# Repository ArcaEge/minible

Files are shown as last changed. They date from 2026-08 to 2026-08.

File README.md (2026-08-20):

<div align="center">
    <h1>
        minible
    </h1>
    <p>
        <strong>
            very mini devboard with BLE and USB
        </strong>
    </p>
    <p>
        <a href="#features">features</a> •
        <a href="#pcb">PCB</a> •
        <a href="#schematics">schematics</a>
    </p>
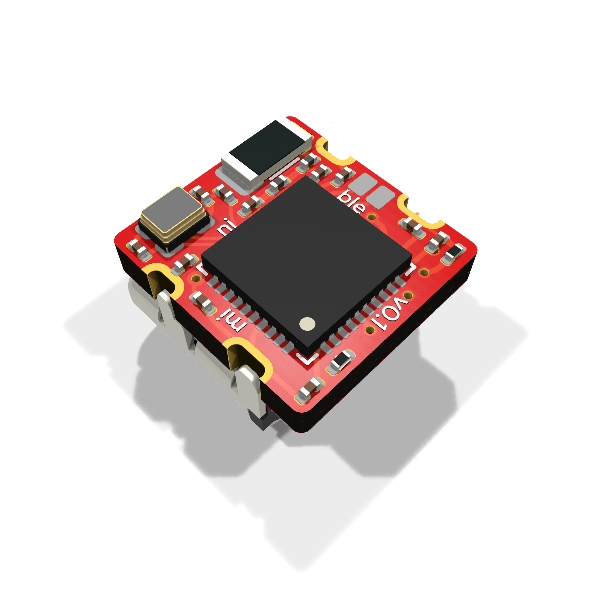
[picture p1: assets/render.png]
render
    
    PCB
</div>

## features

- tiny! just 8.5*9mm
- based on the nRF52833
- USB-C (full speed)
- 2 GPIOs (1 analog input)
    - P0.05, P0.11
- BLE, Thread, Matter, ANT support

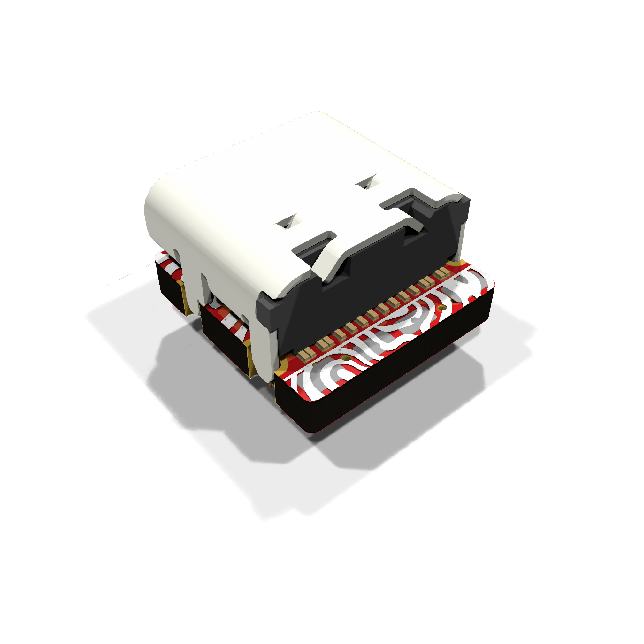
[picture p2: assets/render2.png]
render


## PCB

Production and BOM files are under `production/`

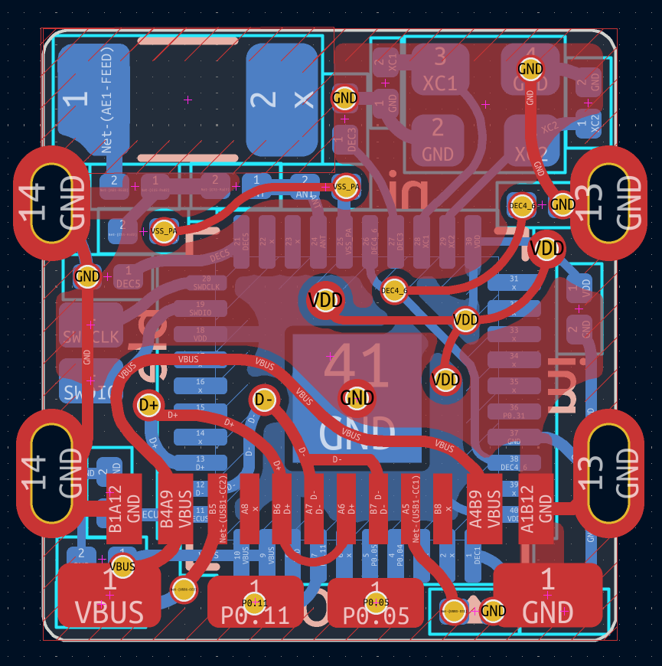
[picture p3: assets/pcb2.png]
PCB


## schematics

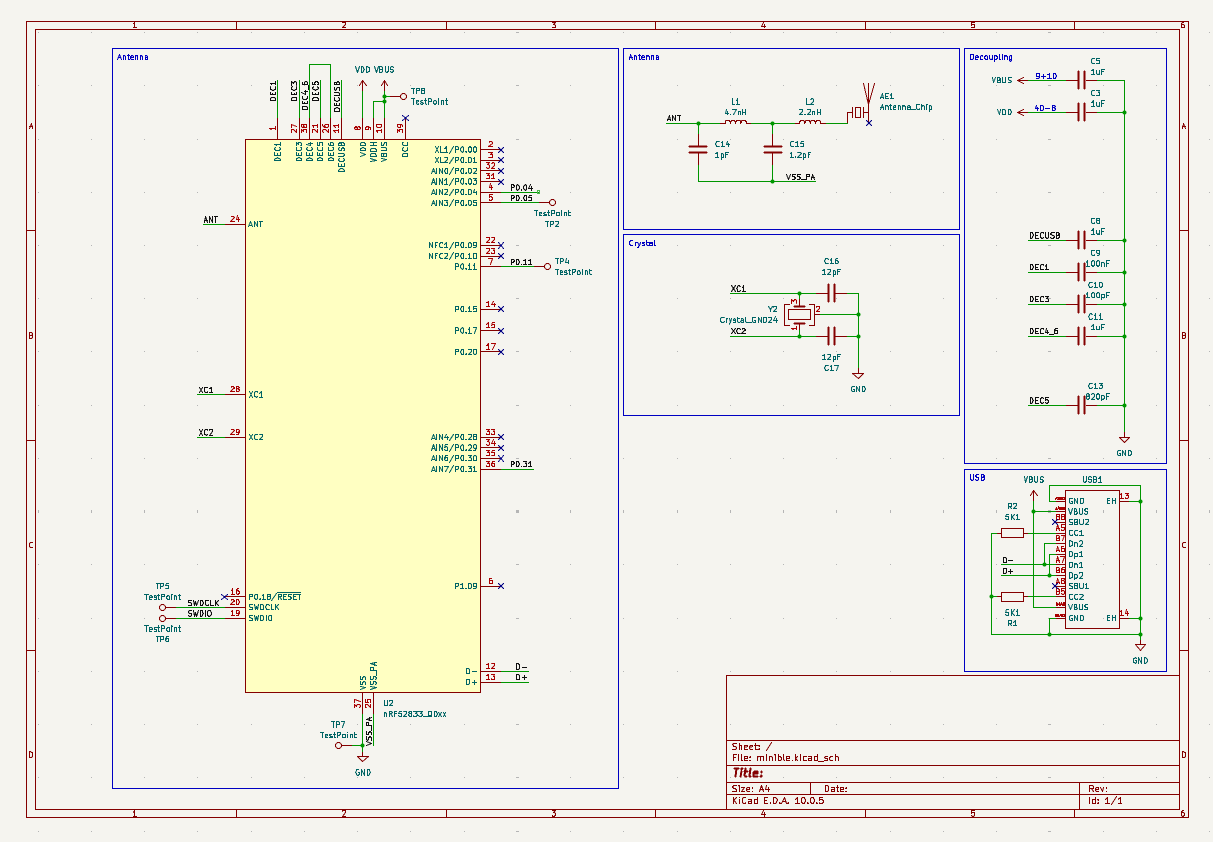
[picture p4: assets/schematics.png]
schematics


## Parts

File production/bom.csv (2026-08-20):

Reference | Qty | Value | Supplier | Supplier Part | Supplier Part URL | Footprint | Datasheet
AE1 | 1 | Antenna_Chip | LCSC | C127620 | https://www.lcsc.com/product-detail/C127620.html | Resistor_SMD:R_1206_3216Metric
C3,C5,C8,C11 | 4 | 1uF | LCSC | C76930 | https://www.lcsc.com/product-detail/C76930.html | Capacitor_SMD:C_0201_0603Metric
C9 | 1 | 100nF | LCSC | C307380 | https://www.lcsc.com/product-detail/C307380.html | Capacitor_SMD:C_0201_0603Metric
C10 | 1 | 100pF | LCSC | C272870 | https://www.lcsc.com/product-detail/C272870.html | Capacitor_SMD:C_0201_0603Metric
C13 | 1 | 820pF | LCSC | C2836759 | https://www.lcsc.com/product-detail/C2836759.html | Capacitor_SMD:C_0201_0603Metric
C14 | 1 | 1pF | LCSC | C20069198 | https://www.lcsc.com/product-detail/C20069198.html | Capacitor_SMD:C_0201_0603Metric
C15 | 1 | 1.2pF | LCSC | C48642883 | https://www.lcsc.com/product-detail/C48642883.html | Capacitor_SMD:C_0201_0603Metric
C16,C17 | 2 | 12pF | LCSC | C50391 | https://www.lcsc.com/product-detail/C50391.html | Capacitor_SMD:C_0201_0603Metric
L1 | 1 | 4.7nH | LCSC | C3910459 | https://www.lcsc.com/product-detail/C3910459.html | Inductor_SMD:L_0201_0603Metric
L2 | 1 | 2.2nH | LCSC | C52109740 | https://www.lcsc.com/product-detail/C52109740.html | Inductor_SMD:L_0201_0603Metric
R1,R2 | 2 | 5K1 | LCSC | C473460 | https://www.lcsc.com/product-detail/C473460.html | Resistor_SMD:R_0201_0603Metric
U2 | 1 | nRF52833_QDxx | LCSC | C2895249 | https://www.lcsc.com/product-detail/C2895249.html | Package_DFN_QFN:QFN-40-1EP_5x5mm_P0.4mm_EP3.6x3.6mm | https://infocenter.nordicsemi.com/pdf/nRF52833_PS_v1.5.pdf
USB1 | 1 |  | LCSC | C2765186 | https://www.lcsc.com/product-detail/C2765186.html | EasyEDA_Lib:USB-C-SMD_TYPE-C-16PIN-2MD-073 | https://item.szlcsc.com/datasheet/TYPE-C%252016PIN%25202MD(073)/2901843.html
Y2 | 1 | Crystal_GND24 | LCSC | C49158176 | https://www.lcsc.com/product-detail/C49158176.html | Crystal:Crystal_SMD_2016-4Pin_2.0x1.6mm | https://www.lcsc.com/datasheet/C49158176.pdf

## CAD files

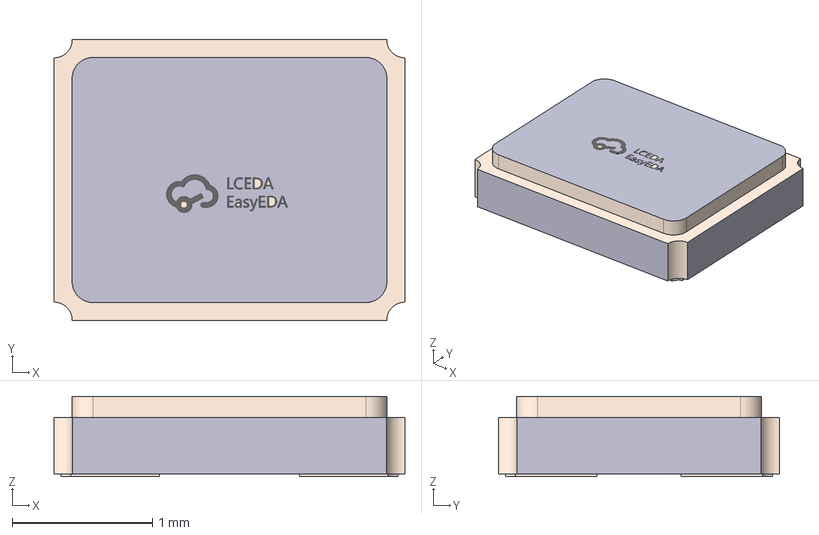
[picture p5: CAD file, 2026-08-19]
pcb/EASYEDA_MODELS/OSC-SMD_4P-L2.5-W2.0-H0.6.step
2.50 x 2.00 x 0.571 mm

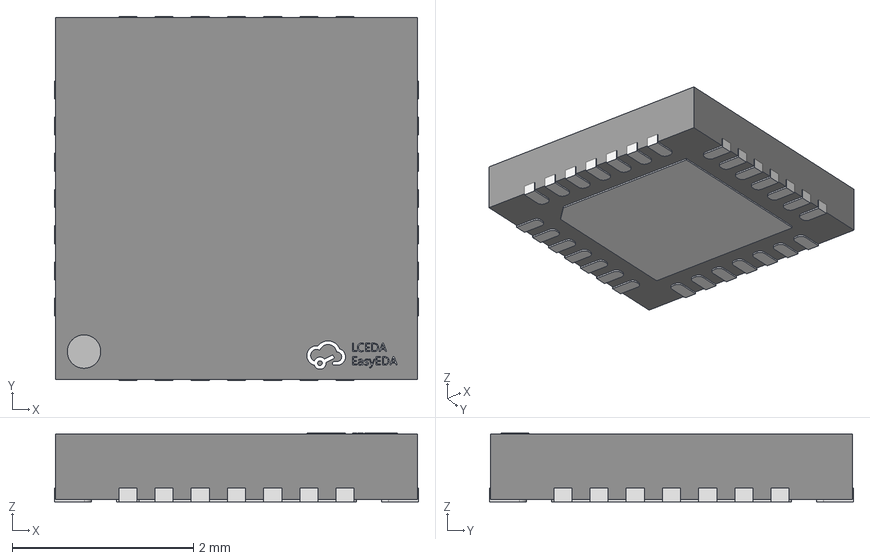
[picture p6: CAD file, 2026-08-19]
pcb/EASYEDA_MODELS/QFN-28_L4.0-W4.0-P0.40-BL-EP2.7.step
4.02 x 4.02 x 0.76 mm

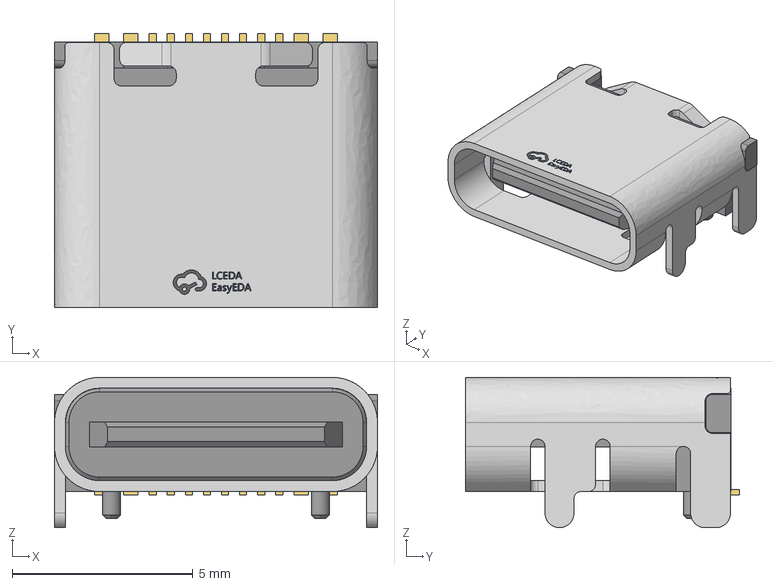
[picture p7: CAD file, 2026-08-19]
pcb/EASYEDA_MODELS/USB-C-SMD_TYPE-C-6PIN-2MD-073.step
8.94 x 7.58 x 4.16 mm

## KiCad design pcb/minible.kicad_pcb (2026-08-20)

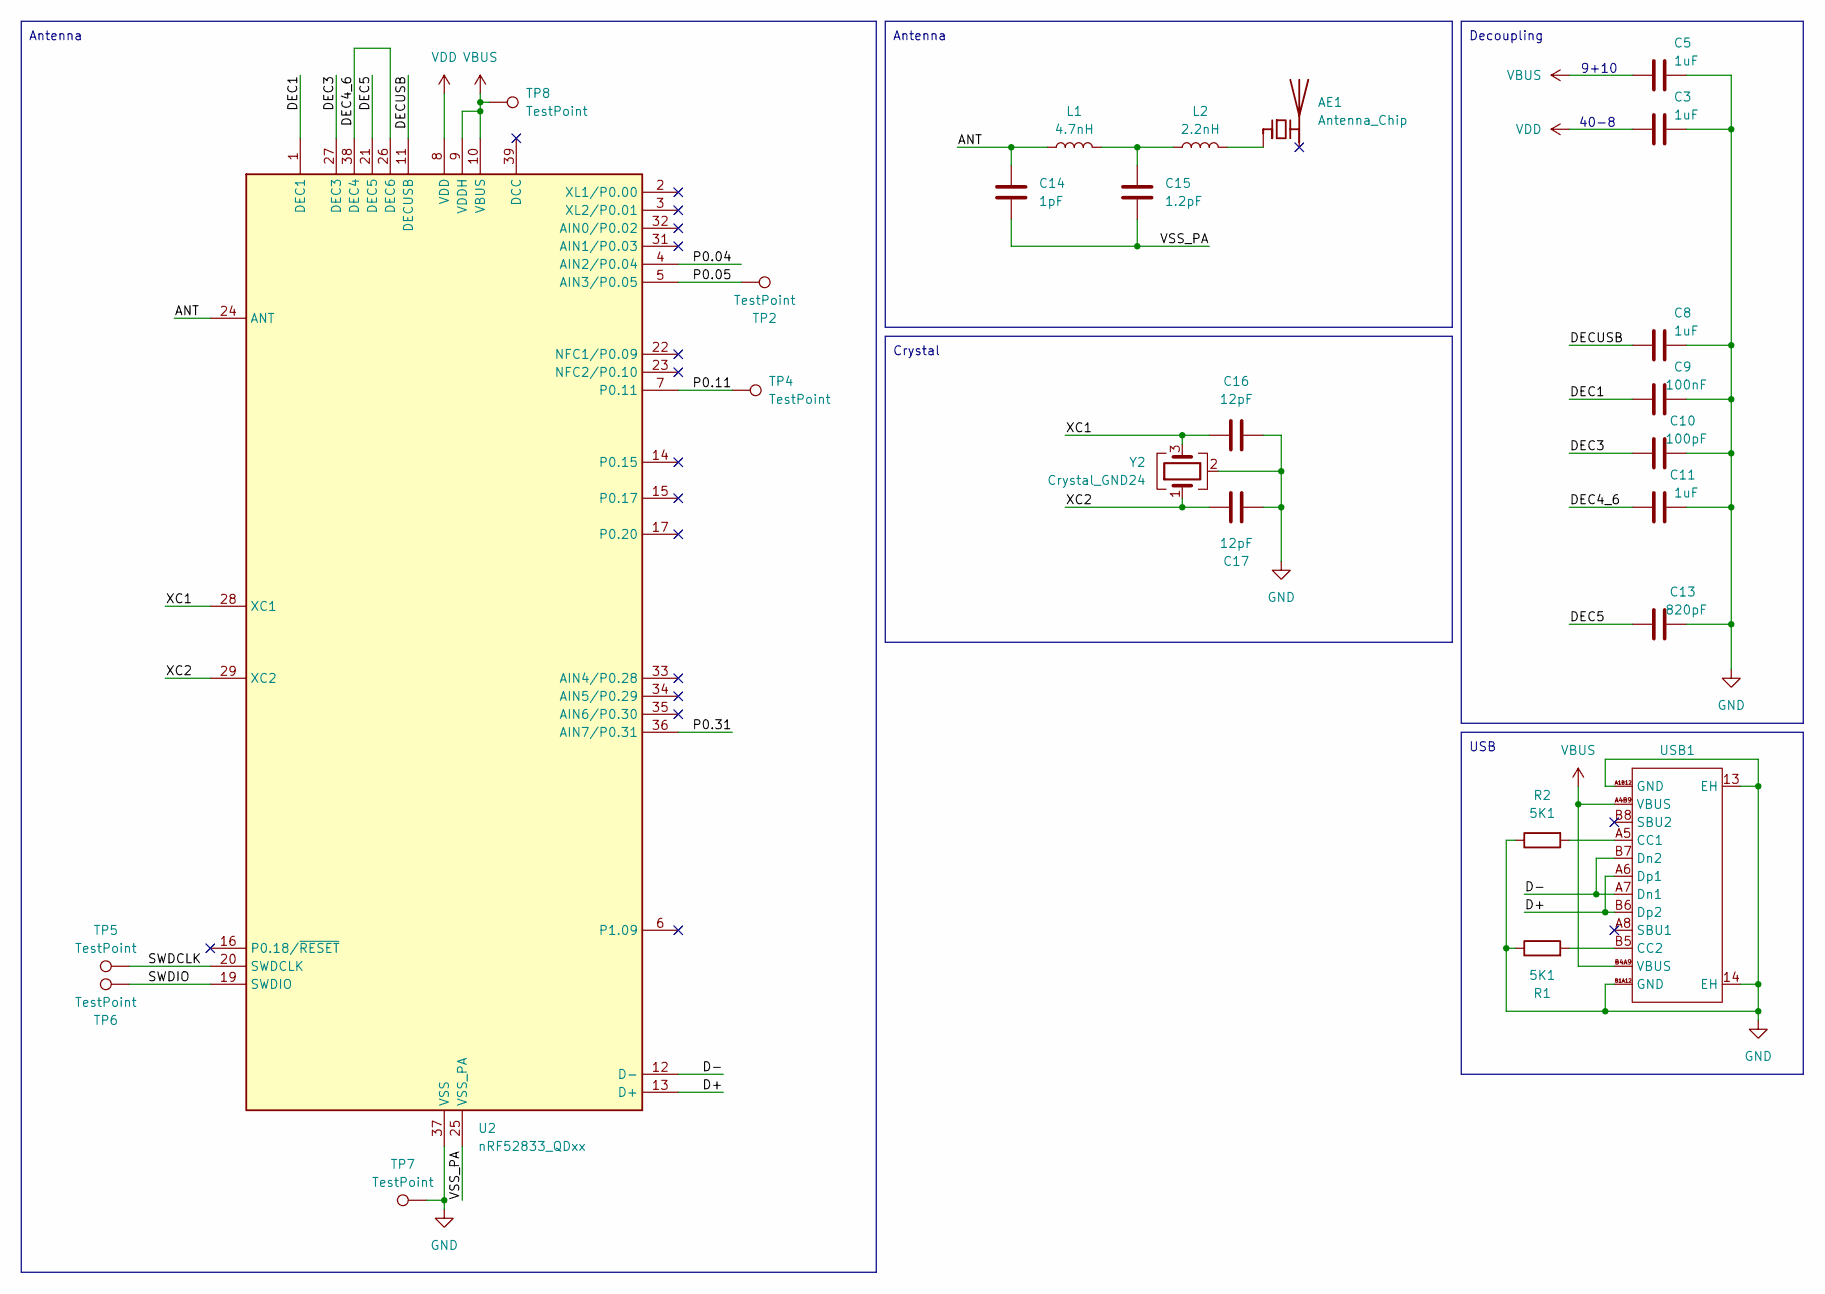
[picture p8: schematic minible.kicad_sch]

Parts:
AE1: Antenna_Chip; R_1206_3216Metric
C3, C5, C8, C11: 1uF; C_0201_0603Metric
C9: 100nF; C_0201_0603Metric
C10: 100pF; C_0201_0603Metric
C13: 820pF; C_0201_0603Metric
C14: 1pF; C_0201_0603Metric
C15: 1.2pF; C_0201_0603Metric
C16, C17: 12pF; C_0201_0603Metric
L1: 4.7nH; L_0201_0603Metric
L2: 2.2nH; L_0201_0603Metric
R1, R2: 5K1; R_0201_0603Metric
TP2, TP4, TP5, TP6, TP7, TP8: TestPoint; TestPoint_Keystone_5015_Micro_Mini
U2: nRF52833_QDxx; QFN-40-1EP_5x5mm_P0.4mm_EP3.6x3.6mm
USB1: USB-C-SMD_TYPE-C-16PIN-2MD-073; Manufacturer Part TYPE-C 16PIN 2MD(073); LCSC Part Name Type-C 母 卧贴
Y2: Crystal_GND24; Crystal_SMD_2016-4Pin_2.0x1.6mm

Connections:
/ANT: C14.2, L1.1, U2.24 (ANT)
/D+: U2.13 (D+), USB1.A6 (Dp1), USB1.B6 (Dp2)
/D-: U2.12 (D-), USB1.A7 (Dn1), USB1.B7 (Dn2)
/DEC1: C9.1, U2.1 (DEC1)
/DEC3: C10.1, U2.27 (DEC3)
/DEC4_6: C11.1, U2.26 (DEC6), U2.38 (DEC4)
/DEC5: C13.1, U2.21 (DEC5)
/DECUSB: C8.1, U2.11 (DECUSB)
/P0.04: U2.4 (AIN2/P0.04)
/P0.05: TP2.1 (1_1), U2.5 (AIN3/P0.05)
/P0.11: TP4.1 (1_1), U2.7 (P0.11)
/P0.31: U2.36 (AIN7/P0.31)
/SWDCLK: TP5.1 (1_1), U2.20 (SWDCLK)
/SWDIO: TP6.1 (1_1), U2.19 (SWDIO)
/VSS_PA: C14.1, C15.1, U2.25 (VSS_PA)
/XC1: C16.2, U2.28 (XC1), Y2.3
/XC2: C17.1, U2.29 (XC2), Y2.1
GND: C3.2, C5.2, C8.2, C9.2, C10.2, C11.2, C13.2, C16.1, C17.2, R1.1, R2.1, TP7.1 (1_1), U2.37 (VSS), U2.41 (VSS), USB1.13 (EH), USB1.14 (EH), USB1.A1B12 (GND), USB1.B1A12 (GND), Y2.2 (G), Y2.4 (G)
unnamed: AE1.1 (FEED_1), L2.2
unnamed: C15.2, L1.2, L2.1
unnamed: R2.2, USB1.A5 (CC1)
unnamed: R1.2, USB1.B5 (CC2)
VBUS: C5.1, TP8.1 (1_1), U2.9 (VDDH), U2.10 (VBUS), USB1.A4B9 (VBUS), USB1.B4A9 (VBUS)
VDD: C3.1, U2.8 (VDD), U2.18 (VDD), U2.30 (VDD), U2.40 (VDD)

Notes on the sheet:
40-8
Crystal
Antenna
9+10
Decoupling
USB

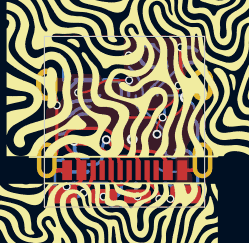
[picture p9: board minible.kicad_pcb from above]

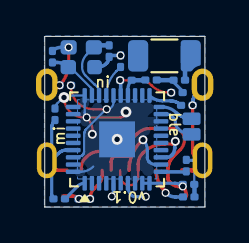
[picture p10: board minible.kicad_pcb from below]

Board: 2 copper layers, 8.9 x 9.5 mm, 25 parts (20 on the bottom side), 22 nets.

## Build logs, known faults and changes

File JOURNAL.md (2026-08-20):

## Did research and started laying out schematic
Aug 18 • 1h30

I started by deciding which nRF to use and spent some time comparing. Looking at the featureset, the nRF52833 seemed pretty good: built-in USB, no need to use an external LDO, and all of this:



Looks like only the nRF52833 and nRF52840 have USB support and this is cheaper, so I'll be using this.

## Finished schematics
Aug 19 • 2h

Schematics are done! I've looked through and added LCSC part numbers too, will be using some of my own parts that I already have. The rest of the parts will be 0402 to save on space and cost.



Did some cost optimising too, switching to 0402s here and there. The current price is around $13 but if I bought in bulk (1000 boards) it'd be down to ~$3.80 per board - so pretty decent.

## Finished PCB, after many iterations
Aug 19 • 9h

Initially made this, a somewhat compact but still not that dense board:



Then I decided I should make it as tiny as possible, because [this thing](https://github.com/Dieu-de-l-elec/AngstromIO-devboard) exists and I want to beat that. They made a 9x8.9mm devboard and I wanted to see if I could do better.



The layout and routing took a while but it's finally done! I spent a bunch of time rearranging everything to squeeze things closer together and it ended up being 8.9x9.5mm. Half a millimetre more in height but we also have Bluetooth, USB data and a much more powerful processor :)



A lot of jank was involved to get here - just look at the antenna 1206 pad :)

## Polishing up + curvy traces
Aug 20 • 5h

Added curvy traces - they look really nice on the board! Also added some silkscreen wave patterns:





The pads also got rearranged a bit so they're larger, also I had to switch to larger vias to save cost. The board is done, it ended up being 8.9*9.5mm - there isn't enough area to pack things tighter and still have space for pads.

It really is quite tiny...



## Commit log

2026-08-19 Finish schematics
    [OSC-SMD_4P-L2.5-W2.0-H0.6.step, QFN-28_L4.0-W4.0-P0.40-BL-EP2.7.step, USB-C-SMD_TYPE-C-6PIN-2MD-073.step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]
2026-08-20 finish pcb
    [minible.kicad_pcb, minible.kicad_sch]
2026-08-20 Add LCSC URLs
    [minible.kicad_pcb, minible.kicad_sch]
2026-08-20 Update gitignore
    [bom.csv, designators.csv, positions.csv]
2026-08-20 Update BOM
    [bom.csv]
2026-08-20 Organise repo
    [OSC-SMD_4P-L2.5-W2.0-H0.6.step, QFN-28_L4.0-W4.0-P0.40-BL-EP2.7.step, USB-C-SMD_TYPE-C-6PIN-2MD-073.step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]
